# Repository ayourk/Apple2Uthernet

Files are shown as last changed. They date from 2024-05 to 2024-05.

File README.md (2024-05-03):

# Uthernet II

* The a2RetroSystems [Uthernet II](http://a2retrosystems.com/products.htm) product page
* The Uthernet II [User’s and Programmer’s Manual](http://dserver.macgui.com/Uthernet%20II%20manual%20draft.pdf)
* An Uthernet II [Applications Overview](http://www.a2retrosystems.com/downloads.htm)
* Some Uthernet II [Programming Infos](https://github.com/a2retrosystems/uthernet2/wiki)

## Description
Recreation of the Uthernet II Apple II Network Expansion Card using KiCAD 6.0.x.<br />
This version is a recreation of the Uthernet II board with the 80-pin WizNet W5100 chip.  
This version is NOT compatible with the [light pipe system](https://www.tindie.com/products/option8/uthernet-ii-light-pipe/) of the original.<br />
The cutout on the right is to accommodate [Adafruit's Panel Mount Ethernet Extension Cable](https://www.adafruit.com/product/909) if the card is put into Slot #2 on an Apple IIgs. <br />
Very little about the layout may need to be changed. <br />
Some parts may be difficult to source for PCB assembly unless you preorder them in advance.

### PCB Layout
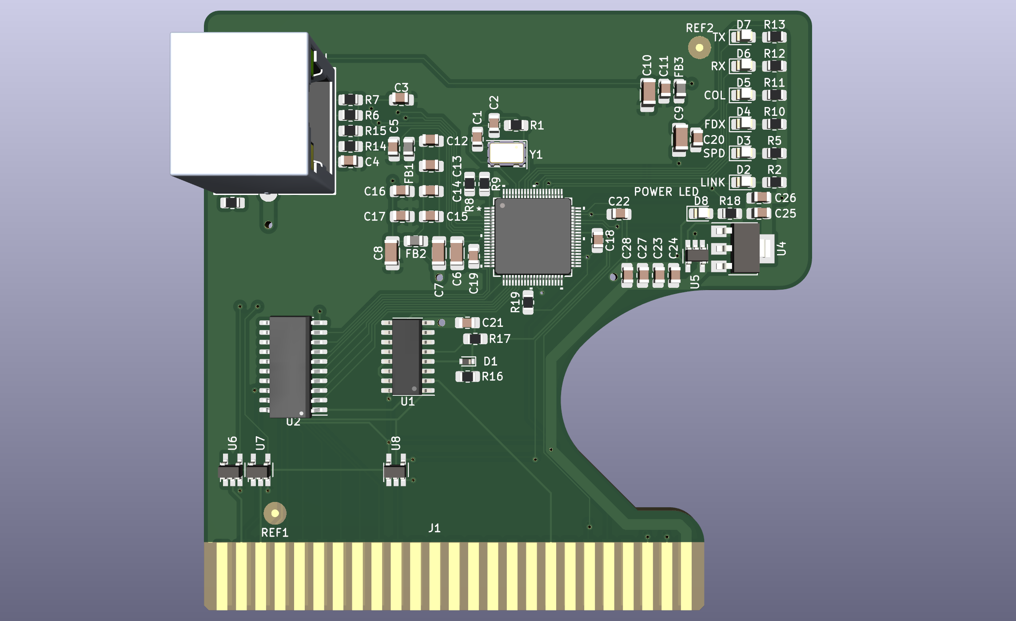
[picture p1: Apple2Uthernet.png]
Uthernet Board Image Apple II Network Expansion Card


### See Also
[Apple_II_Expansion Card_Specification](https://github.com/ayourk/Apple2Proto/raw/master/Apple_II_ExpansionCard_Spec.txt)

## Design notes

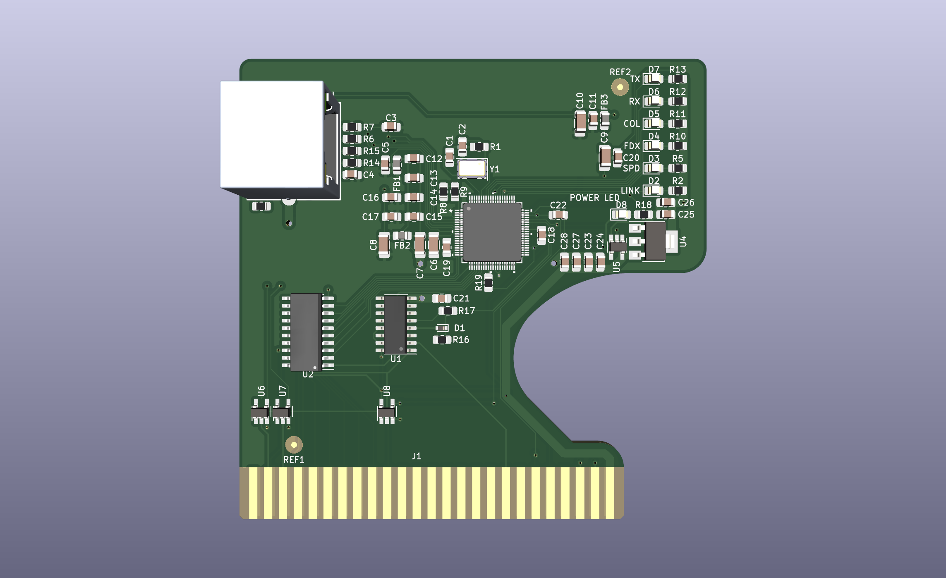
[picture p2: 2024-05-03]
Apple2Uthernet-Social.png

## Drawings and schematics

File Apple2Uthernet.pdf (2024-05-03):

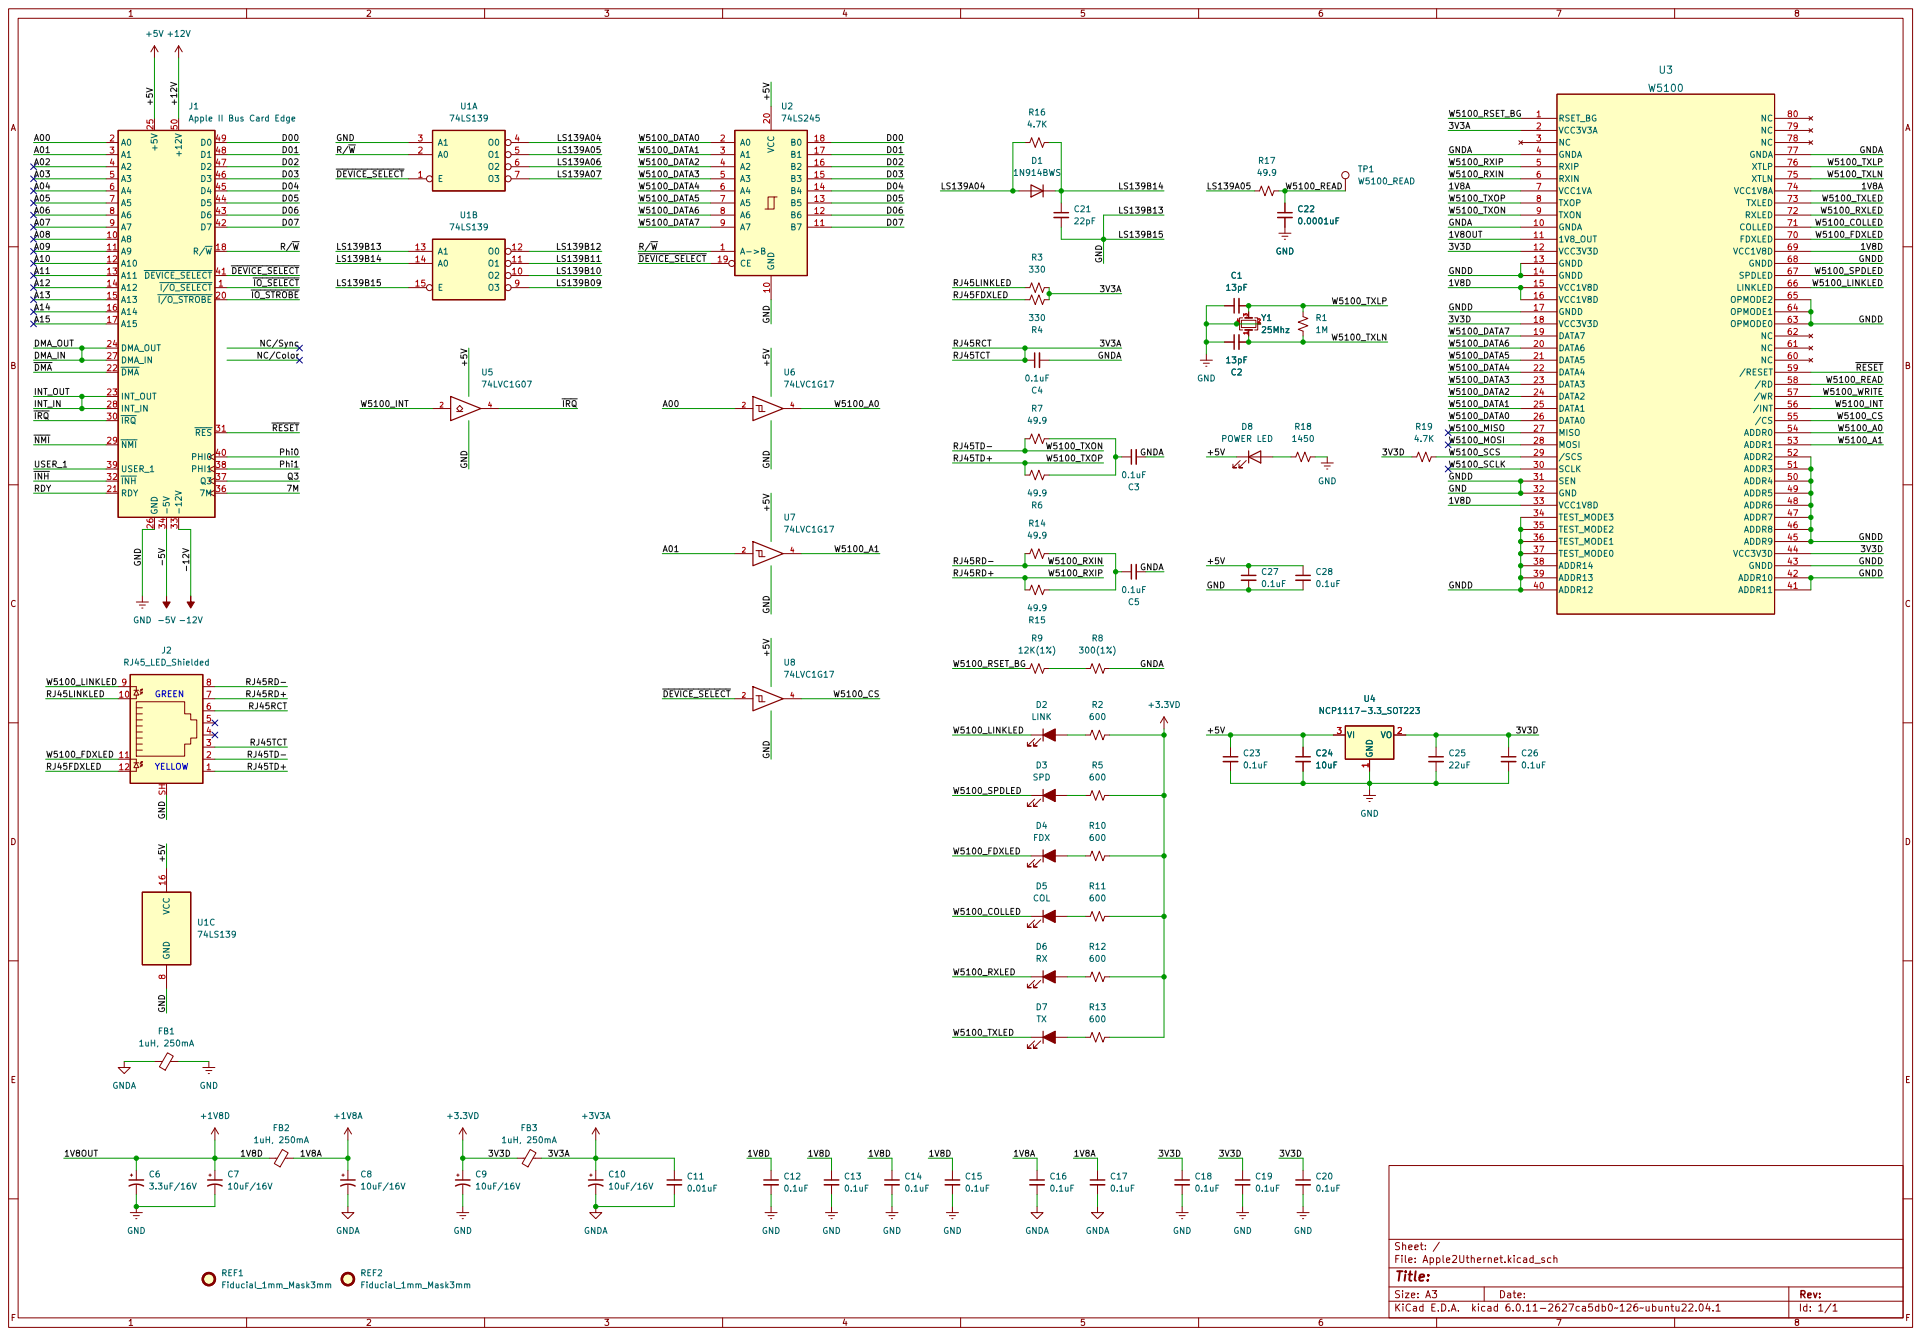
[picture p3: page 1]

Id: 1/1 Title: File: Apple2Uthernet.kicad_sch Sheet: / C11

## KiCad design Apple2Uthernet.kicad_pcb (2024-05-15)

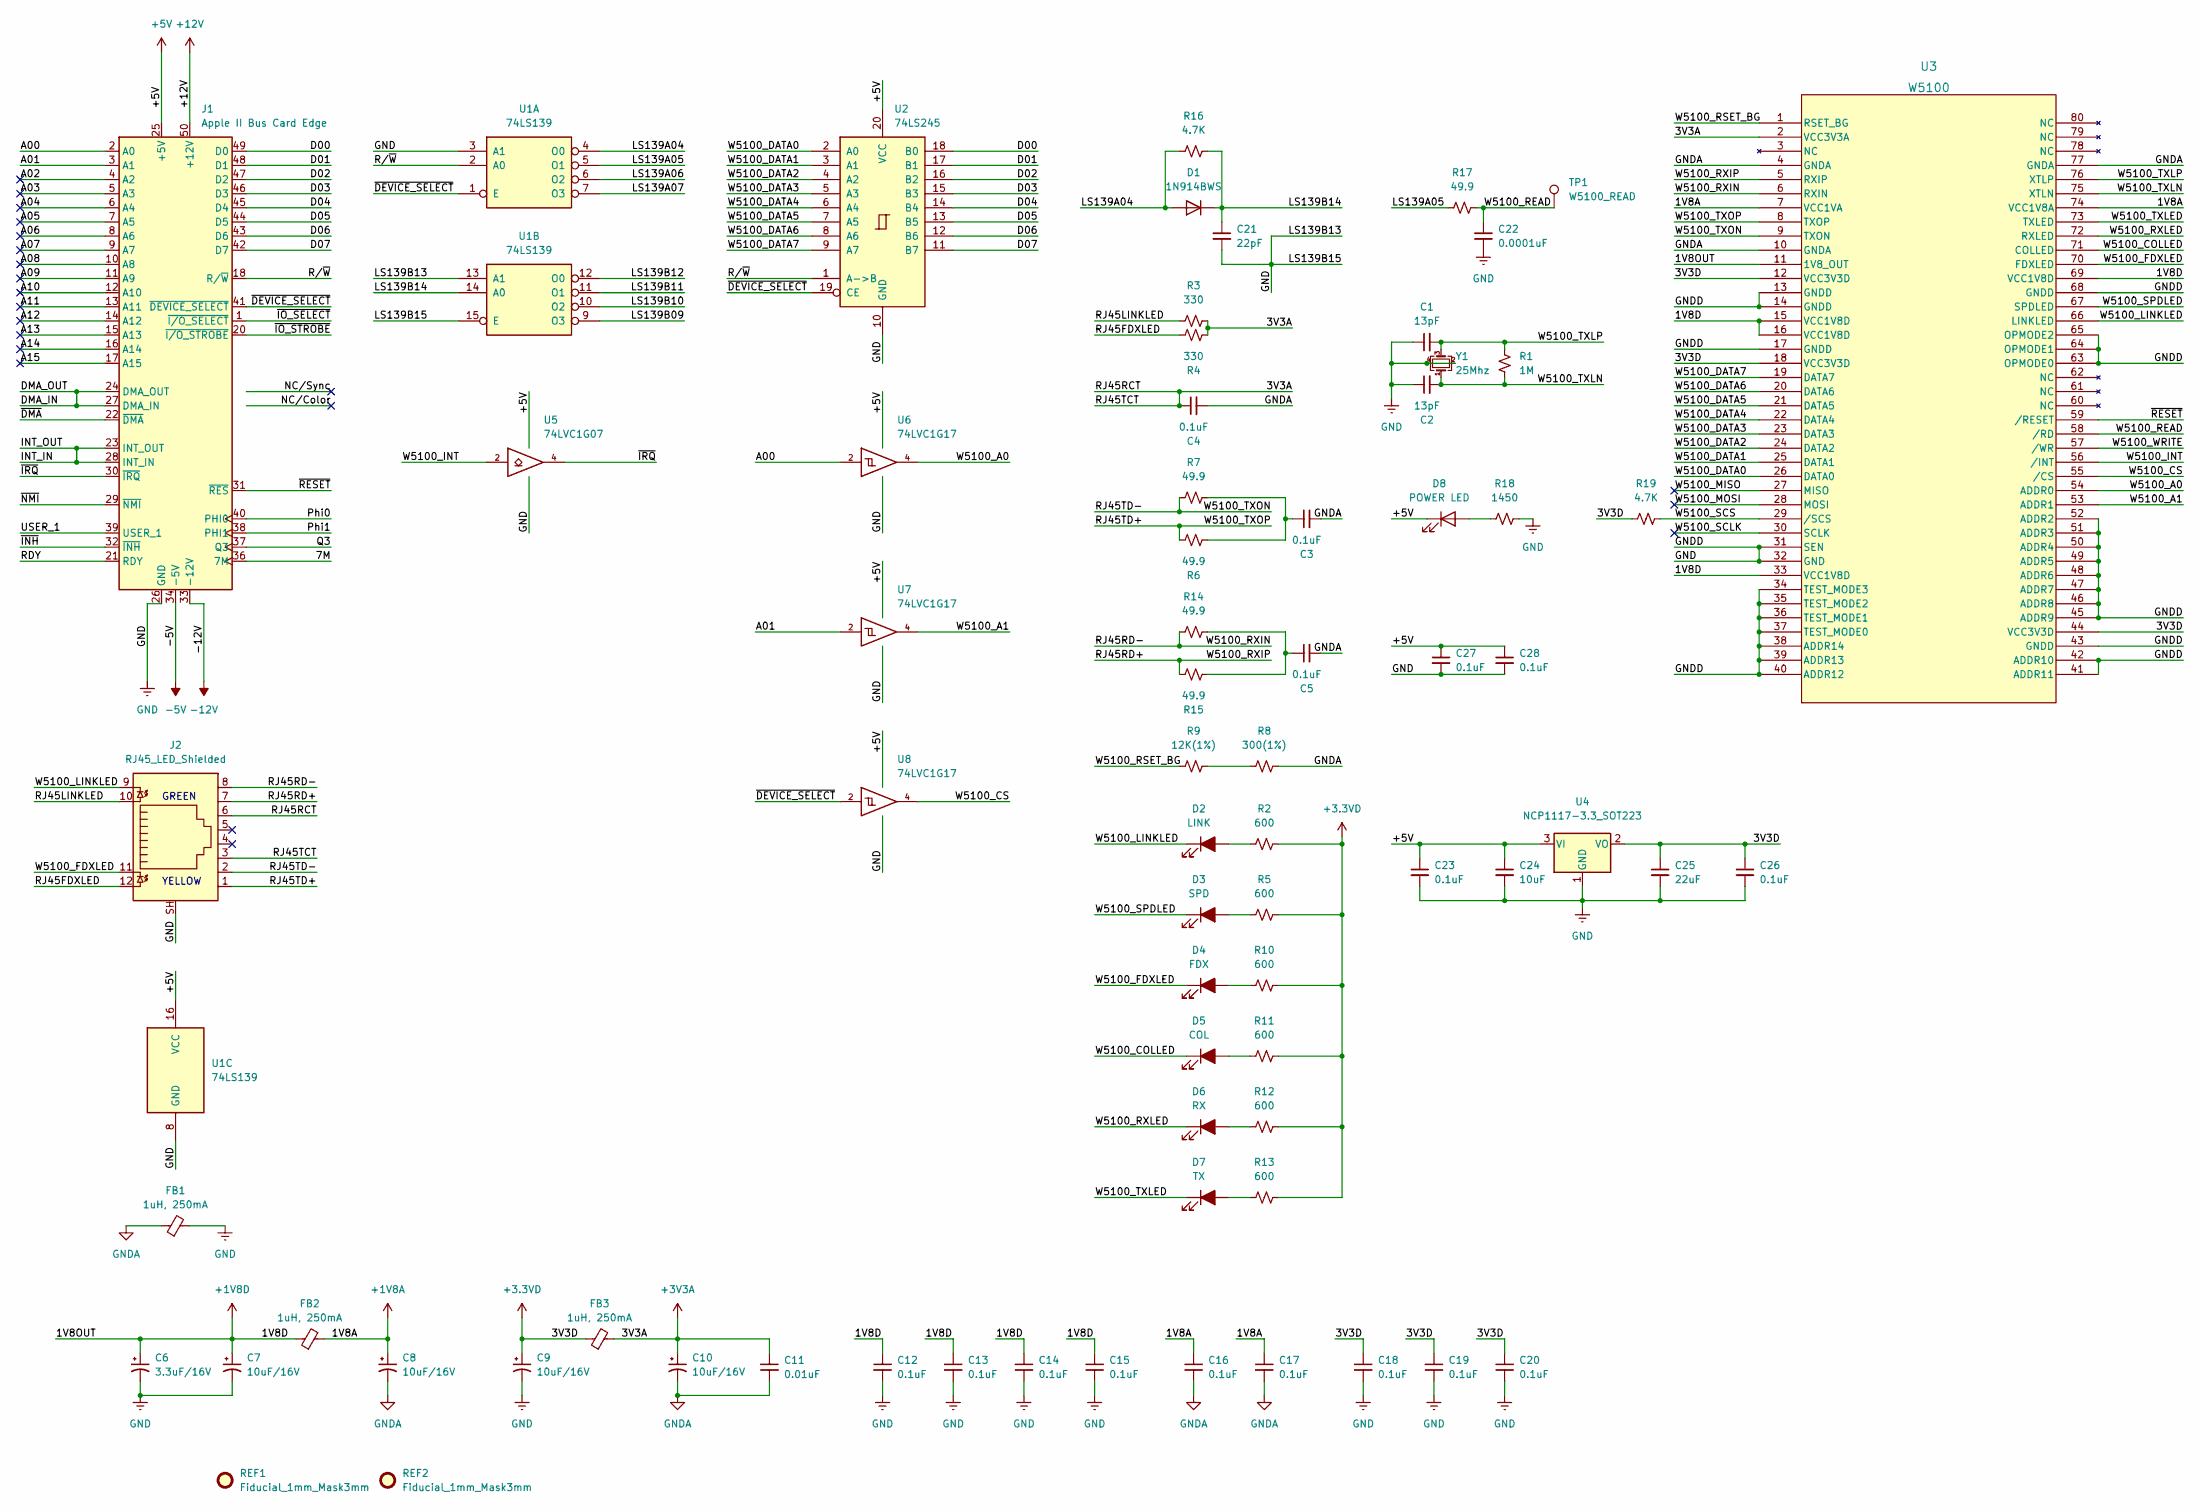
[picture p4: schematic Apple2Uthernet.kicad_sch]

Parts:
C1, C2: 13pF; C_0805_2012Metric_Pad1.18x1.45mm_HandSolder; MPN CC0805JRNPO9BN130; LCSC C519918
C3, C4, C5, C12, C13, C14, C15, C16, C17, C18, C19, C20, C23, C26, C27, C28: 0.1uF; C_0805_2012Metric_Pad1.18x1.45mm_HandSolder; MPN CL21B104KBCNNNC; LCSC C1711
C6: 3.3uF/16V; C_1206_3216Metric_Pad1.33x1.80mm_HandSolder; MPN T491A335M016AT; LCSC C1954959
C7, C8, C9, C10: 10uF/16V; C_1206_3216Metric_Pad1.33x1.80mm_HandSolder; MPN T494A106M016AT; LCSC C2798061
C11: 0.01uF; C_0805_2012Metric_Pad1.18x1.45mm_HandSolder; MPN CL21C103JBFNNNE; LCSC C27071
C21: 22pF; C_0805_2012Metric_Pad1.18x1.45mm_HandSolder; MPN CL21C220JB61PNC; LCSC C472837
C22: 0.0001uF; C_0805_2012Metric_Pad1.18x1.45mm_HandSolder; MPN CL21C101JBANNNC; LCSC C1790
C24: 10uF; C_0805_2012Metric_Pad1.18x1.45mm_HandSolder; MPN CL21B106KAYQNNE; LCSC C3039694
C25: 22uF; C_0805_2012Metric_Pad1.18x1.45mm_HandSolder; MPN CL21A226MAYNNNE; LCSC C602037
D1: 1N914BWS; D_SOD-523; MPN 1N914BWS; LCSC C2836064
D2: LINK; LED_0805_2012Metric_Pad1.15x1.40mm_HandSolder; MPN APT2012CGCK; LCSC C5875740
D3: SPD; LED_0805_2012Metric_Pad1.15x1.40mm_HandSolder; MPN APT2012CGCK; LCSC C5875740
D4: FDX; LED_0805_2012Metric_Pad1.15x1.40mm_HandSolder; MPN APT2012CGCK; LCSC C5875740
D5: COL; LED_0805_2012Metric_Pad1.15x1.40mm_HandSolder; MPN APT2012CGCK; LCSC C5875740
D6: RX; LED_0805_2012Metric_Pad1.15x1.40mm_HandSolder; MPN APT2012CGCK; LCSC C5875740
D7: TX; LED_0805_2012Metric_Pad1.15x1.40mm_HandSolder; MPN APT2012CGCK; LCSC C5875740
D8: POWER LED; LED_0805_2012Metric_Pad1.15x1.40mm_HandSolder; MPN APT2012CGCK; LCSC C5875740
FB1, FB2, FB3: 1uH, 250mA; L_0805_2012Metric_Pad1.15x1.40mm_HandSolder; MPN MLZ2012A1R0WT000; LCSC C88171
J1: Apple II Bus Card Edge; Bus_Apple_II_Card
J2: RJ45_LED_Shielded; RJ45-TH_XKB_X12ADAB1A3DY1027; MPN X12ADAB1A3DY1027; LCSC C2916459
R1: 1M; R_0805_2012Metric_Pad1.20x1.40mm_HandSolder; MPN ERJ-P06F1004V; LCSC C441997
R2, R5, R10, R11, R12, R13: 600; R_0805_2012Metric_Pad1.20x1.40mm_HandSolder; MPN ERJ-6ENF5900V; LCSC C2077453
R3, R4: 330; R_0805_2012Metric_Pad1.20x1.40mm_HandSolder; MPN ERJ-6ENF3300V; LCSC C410007
R6, R7, R14, R15, R17: 49.9; R_0805_2012Metric_Pad1.20x1.40mm_HandSolder; MPN CRCW080549R9FKEAHP; LCSC C204544
R8: 300(1%); R_0805_2012Metric_Pad1.20x1.40mm_HandSolder; MPN RC0805FR-07300RL; LCSC C114529
R9: 12K(1%); R_0805_2012Metric_Pad1.20x1.40mm_HandSolder; MPN RC0805FR-7W12KL; LCSC C408920
R16, R19: 4.7K; R_0805_2012Metric_Pad1.20x1.40mm_HandSolder; MPN ERJ-P06F4701V; LCSC C441984
R18: 1450; R_0805_2012Metric_Pad1.20x1.40mm_HandSolder; MPN ERJ-6ENF1431V; LCSC C336837
REF1, REF2: Fiducial_1mm_Mask3mm
TP1: W5100_READ
U1: 74LS139; SOP-16_3.9x9.9mm_P1.27mm; MPN XL74LS139; LCSC C521174
U2: 74LS245; SO-20_5.3x12.6mm_P1.27mm; MPN SN74LS245NSR; LCSC C7753
U3: W5100; 80LQFP_W5100_WIZ; MPN W5100; LCSC C18866
U4: NCP1117-3.3_SOT223; SOT-223-3_TabPin2; MPN NCP1117ST33T3G; LCSC C26537
U5: 74LVC1G07; SOT-23-5_HandSoldering; MPN SN74LVC1G07DBVR; LCSC C7829
U6, U7, U8: 74LVC1G17; SOT-23-5_HandSoldering; MPN SN74LVC1G17DBVR; LCSC C7836
Y1: 25Mhz; Crystal_SMD_5032-4Pin_5.0x3.2mm; MPN 405C35B25M00000; LCSC C252362

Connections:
+1V8: C6.1, C7.1, C12.1, C13.1, C14.1, C15.1, FB2.1, U3.11 (1V8_OUT), U3.15 (VCC1V8D), U3.16 (VCC1V8D), U3.33 (VCC1V8D), U3.69 (VCC1V8D)
+1V8A: C8.1, C16.1, C17.1, FB2.2, U3.7 (VCC1VA), U3.74 (VCC1V8A)
+3.3V: C9.1, C18.1, C19.1, C20.1, C25.1, C26.1, FB3.1, R2.2, R5.2, R10.2, R11.2, R12.2, R13.2, R19.1, U3.12 (VCC3V3D), U3.18 (VCC3V3D), U3.44 (VCC3V3D), U4.2 (VO)
+3V3A: C4.1, C10.1, C11.1, FB3.2, J2.3, J2.6, R3.2, R4.2, U3.2 (VCC3V3A)
+5V: C23.1, C24.1, C27.1, C28.1, D8.1 (K), J1.25 (+5V), U1.16 (VCC), U2.20 (VCC), U4.3 (VI), U5.5 (VCC), U6.5 (VCC), U7.5 (VCC), U8.5 (VCC)
+12V: J1.50 (+12V)
-5V: J1.34 (-5V)
-12V: J1.33 (-12V)
/7M: J1.36 (7M)
/A00: J1.2 (A0), U6.2
/A01: J1.3 (A1), U7.2
/A02: J1.4 (A2)
/A03: J1.5 (A3)
/A04: J1.6 (A4)
/A05: J1.7 (A5)
/A06: J1.8 (A6)
/A07: J1.9 (A7)
/A08: J1.10 (A8)
/A09: J1.11 (A9)
/A10: J1.12 (A10)
/A11: J1.13 (A11)
/A12: J1.14 (A12)
/A13: J1.15 (A13)
/A14: J1.16 (A14)
/A15: J1.17 (A15)
/D00: J1.49 (D0), U2.18 (B0)
/D01: J1.48 (D1), U2.17 (B1)
/D02: J1.47 (D2), U2.16 (B2)
/D03: J1.46 (D3), U2.15 (B3)
/D04: J1.45 (D4), U2.14 (B4)
/D05: J1.44 (D5), U2.13 (B5)
/D06: J1.43 (D6), U2.12 (B6)
/D07: J1.42 (D7), U2.11 (B7)
/DMA_IN: J1.24 (DMA_OUT), J1.27 (DMA_IN)
/INT_IN: J1.23 (INT_OUT), J1.28 (INT_IN)
/LS139A04: D1.2 (A), R16.1, U1.4 (O0)
/LS139A05: R17.1, U1.5 (O1)
/LS139A06: U1.6 (O2)
/LS139A07: U1.7 (O3)
/LS139B09: U1.9 (O3)
/LS139B10: U1.10 (O2)
/LS139B11: U1.11 (O1)
/LS139B12: U1.12 (O0)
/LS139B14: C21.1, D1.1 (K), R16.2, U1.14 (A0)
/NC/Color: J1.35 (NC/Color)
/NC/Sync: J1.19 (NC/Sync)
/Phi0: J1.40 (PHI0)
/Phi1: J1.38 (PHI1)
/Q3: J1.37 (Q3)
/RDY: J1.21 (RDY)
/RJ45FDXLED: J2.12, R4.1
/RJ45LINKLED: J2.10, R3.1
/RJ45RD+: J2.7, R15.1, U3.5 (RXIP)
/RJ45RD-: J2.8, R14.1, U3.6 (RXIN)
/RJ45TD+: J2.1, R6.1, U3.8 (TXOP)
/RJ45TD-: J2.2, R7.1, U3.9 (TXON)
/R/~W: J1.18 (R/~W), U1.2 (A0), U2.1 (A->B)
/USER_1: J1.39 (USER_1)
/W5100_A0: U3.54 (ADDR0), U6.4
/W5100_A1: U3.53 (ADDR1), U7.4
/W5100_COLLED: D5.1 (K), U3.71 (COLLED)
/W5100_CS: U3.55 (/CS), U8.4
/W5100_DATA0: U2.2 (A0), U3.26 (DATA0)
/W5100_DATA1: U2.3 (A1), U3.25 (DATA1)
/W5100_DATA2: U2.4 (A2), U3.24 (DATA2)
/W5100_DATA3: U2.5 (A3), U3.23 (DATA3)
/W5100_DATA4: U2.6 (A4), U3.22 (DATA4)
/W5100_DATA5: U2.7 (A5), U3.21 (DATA5)
/W5100_DATA6: U2.8 (A6), U3.20 (DATA6)
/W5100_DATA7: U2.9 (A7), U3.19 (DATA7)
/W5100_FDXLED: D4.1 (K), J2.11, U3.70 (FDXLED)
/W5100_INT: U3.56 (/INT), U5.2
/W5100_LINKLED: D2.1 (K), J2.9, U3.66 (LINKLED)
/W5100_MISO: U3.27 (MISO)
/W5100_MOSI: U3.28 (MOSI)
/W5100_READ: C22.1, R17.2, TP1.1, U3.58 (/RD)
/W5100_RSET_BG: R9.1, U3.1 (RSET_BG)
/W5100_RXLED: D6.1 (K), U3.72 (RXLED)
/W5100_SCLK: U3.30 (SCLK)
/W5100_SCS: R19.2, U3.29 (/SCS)
/W5100_SPDLED: D3.1 (K), U3.67 (SPDLED)
/W5100_TXLED: D7.1 (K), U3.73 (TXLED)
/W5100_TXLN: C2.2, R1.1, U3.75 (XTLN), Y1.1
/W5100_TXLP: C1.2, R1.2, U3.76 (XTLP), Y1.3
/W5100_WRITE: U3.57 (/WR)
/~DEVICE_SELECT: J1.41 (~DEVICE_SELECT), U1.1 (E), U2.19 (CE), U8.2
/~DMA: J1.22 (~DMA)
/~INH: J1.32 (~INH)
/~IO_SELECT: J1.1 (~I/O_SELECT)
/~IO_STROBE: J1.20 (~I/O_STROBE)
/~IRQ: J1.30 (~IRQ), U5.4
/~NMI: J1.29 (~NMI)
/~RESET: J1.31 (~RES), U3.59 (/RESET)
Earth: C1.1, C2.1, C6.2, C7.2, C9.2, C12.2, C13.2, C14.2, C15.2, C18.2, C19.2, C20.2, C21.2, C22.2, C23.2, C24.2, C25.2, C26.2, C27.2, C28.2, FB1.2, J1.26 (GND), J2.SH, R18.2, U1.3 (A1), U1.8 (GND), U1.13 (A1), U1.15 (E), U2.10 (GND), U3.13 (GNDD), U3.14 (GNDD), U3.17 (GNDD), U3.31 (SEN), U3.32 (GND), U3.34 (TEST_MODE3), U3.35 (TEST_MODE2), U3.36 (TEST_MODE1), U3.37 (TEST_MODE0), U3.38 (ADDR14), U3.39 (ADDR13), U3.40 (ADDR12), U3.41 (ADDR11), U3.42 (ADDR10), U3.43 (GNDD), U3.45 (ADDR9), U3.46 (ADDR8), U3.47 (ADDR7), U3.48 (ADDR6), U3.49 (ADDR5), U3.50 (ADDR4), U3.51 (ADDR3), U3.52 (ADDR2), U3.63 (OPMODE0), U3.64 (OPMODE1), U3.65 (OPMODE2), U3.68 (GNDD), U4.1 (GND), U5.3 (GND), U6.3 (GND), U7.3 (GND), U8.3 (GND), Y1.2, Y1.4
GNDA: C3.2, C4.2, C5.2, C8.2, C10.2, C11.2, C16.2, C17.2, FB1.1, R8.2, U3.4 (GNDA), U3.10 (GNDA), U3.77 (GNDA)
unnamed: C3.1, R6.2, R7.2
unnamed: C5.1, R14.2, R15.2
unnamed: D2.2 (A), R2.1
unnamed: D3.2 (A), R5.1
unnamed: D4.2 (A), R10.1
unnamed: D5.2 (A), R11.1
unnamed: D6.2 (A), R12.1
unnamed: D7.2 (A), R13.1
unnamed: D8.2 (A), R18.1
unnamed: R8.1, R9.2

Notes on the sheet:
GREEN
YELLOW

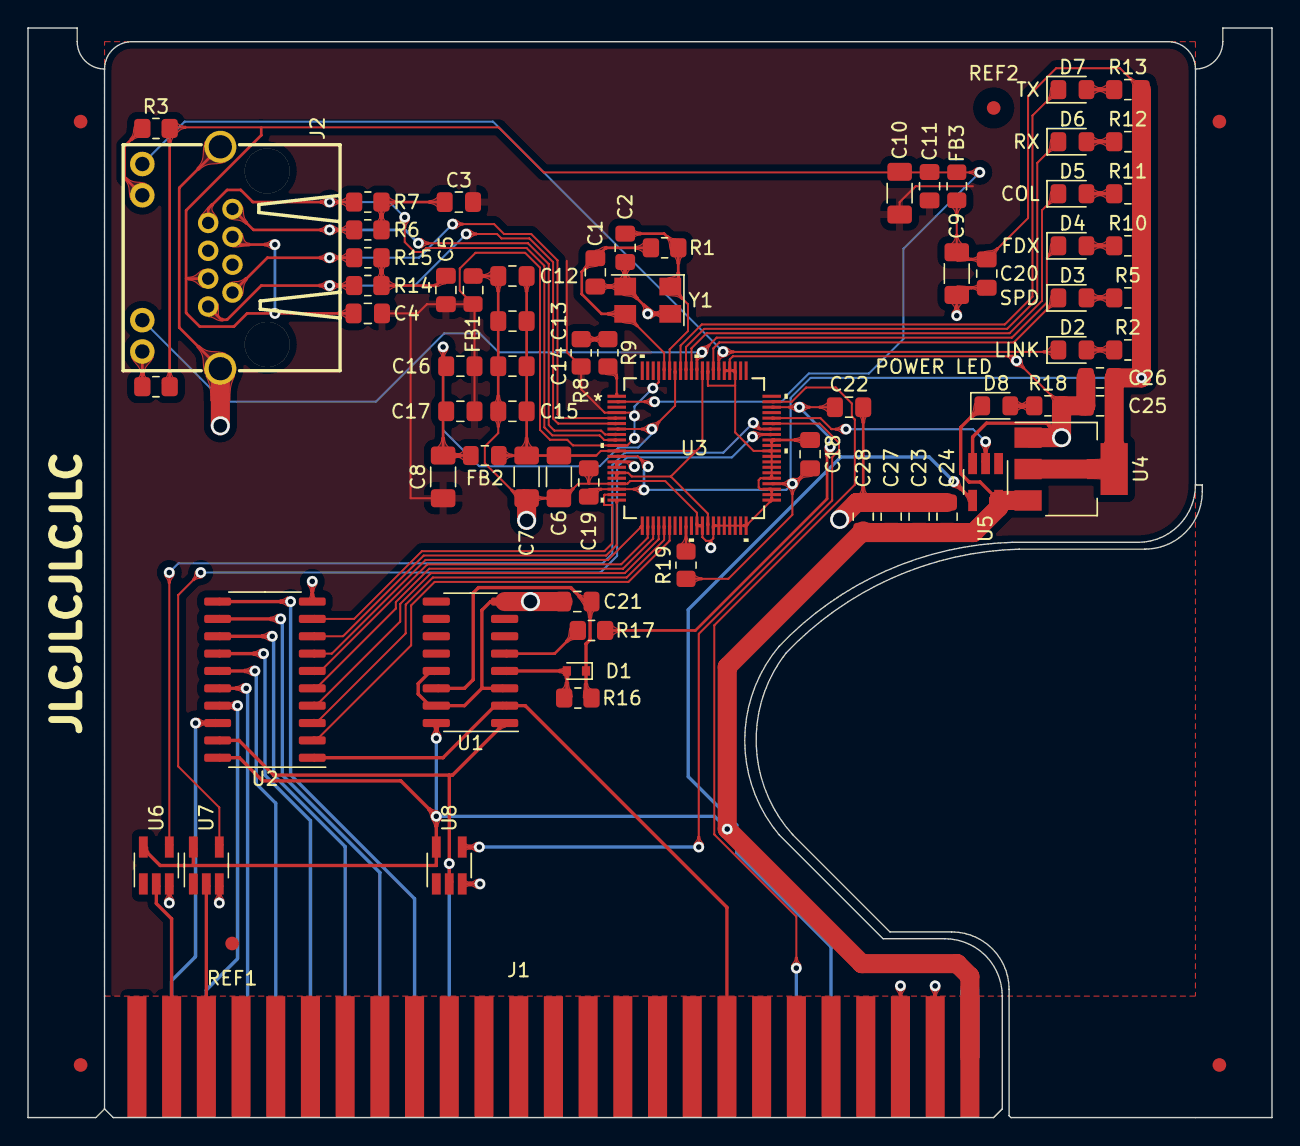
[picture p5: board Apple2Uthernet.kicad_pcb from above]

Board: 2 copper layers, 91.0 x 79.7 mm, 71 parts (0 on the bottom side), 65 nets.

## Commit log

2024-04-07 Initial Commit of KiCAD 6.x files
    [Apple2Uthernet.kicad_pcb, Apple2Uthernet.kicad_sch]
2024-04-07 Update README.md
    Explained differences from original.
    Added picture of PCB layout.
2024-05-03 Updated PCB Layout to accomodate Adafruit Panel Mount Ethernet Extension Cable (PN 909). Made the board more compact. Updated project to render 3D models properly. Added edge rails/fiducials as per h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
    [Apple2Uthernet.kicad_pcb, Apple2Uthernet.kicad_sch]
2024-05-03 Update README.md
    Explained what the cut-out is for.
2024-05-03 Updated missing 3D model for clock crystal for render.
    [Apple2Uthernet.kicad_pcb]
2024-05-14 Make the board taller so that fiducial rails go on the left and right sides.
    [Apple2Uthernet.kicad_pcb]
2024-05-15 Added Fiducial Rails on the Left and Right sides.
    [Apple2Uthernet.kicad_pcb]
2024-05-15 Updated Fiducial rails; Changed 1 resistor due to stocking issues.
    [Apple2Uthernet.kicad_pcb, Apple2Uthernet.kicad_sch]
